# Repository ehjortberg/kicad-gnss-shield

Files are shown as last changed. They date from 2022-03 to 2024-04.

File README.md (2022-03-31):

# GNSS Shield
 - Should fit a Raspberry Pi 40 pin header or compatible.
 - Has footprints for Adafruits zedf9p, Navspark Mini, Navspark NS-HP, and Mikroe gnss-rtk-click
 - Has FTDI and HC-12 connectors for both UART1 and UART2 on the GNSS Modules
 - Connectes UART2 to Raspberry Pi 4 UART2

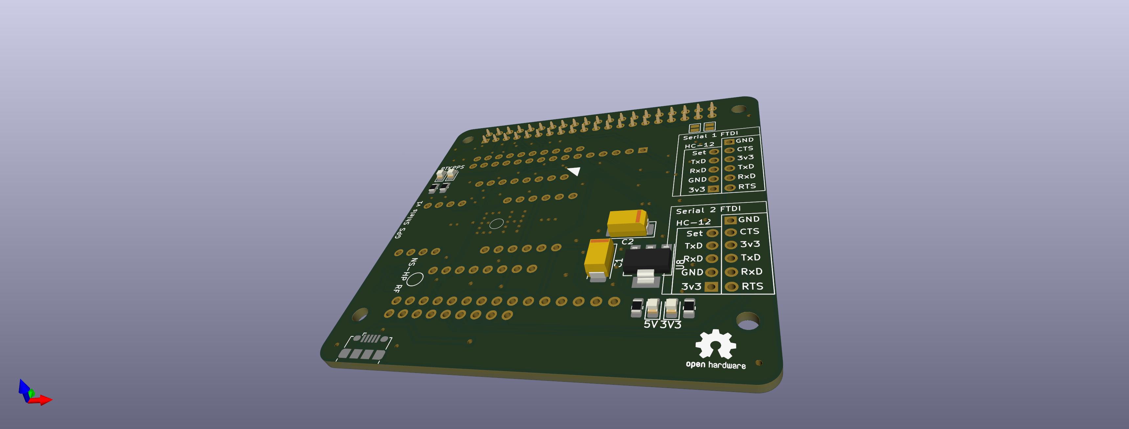
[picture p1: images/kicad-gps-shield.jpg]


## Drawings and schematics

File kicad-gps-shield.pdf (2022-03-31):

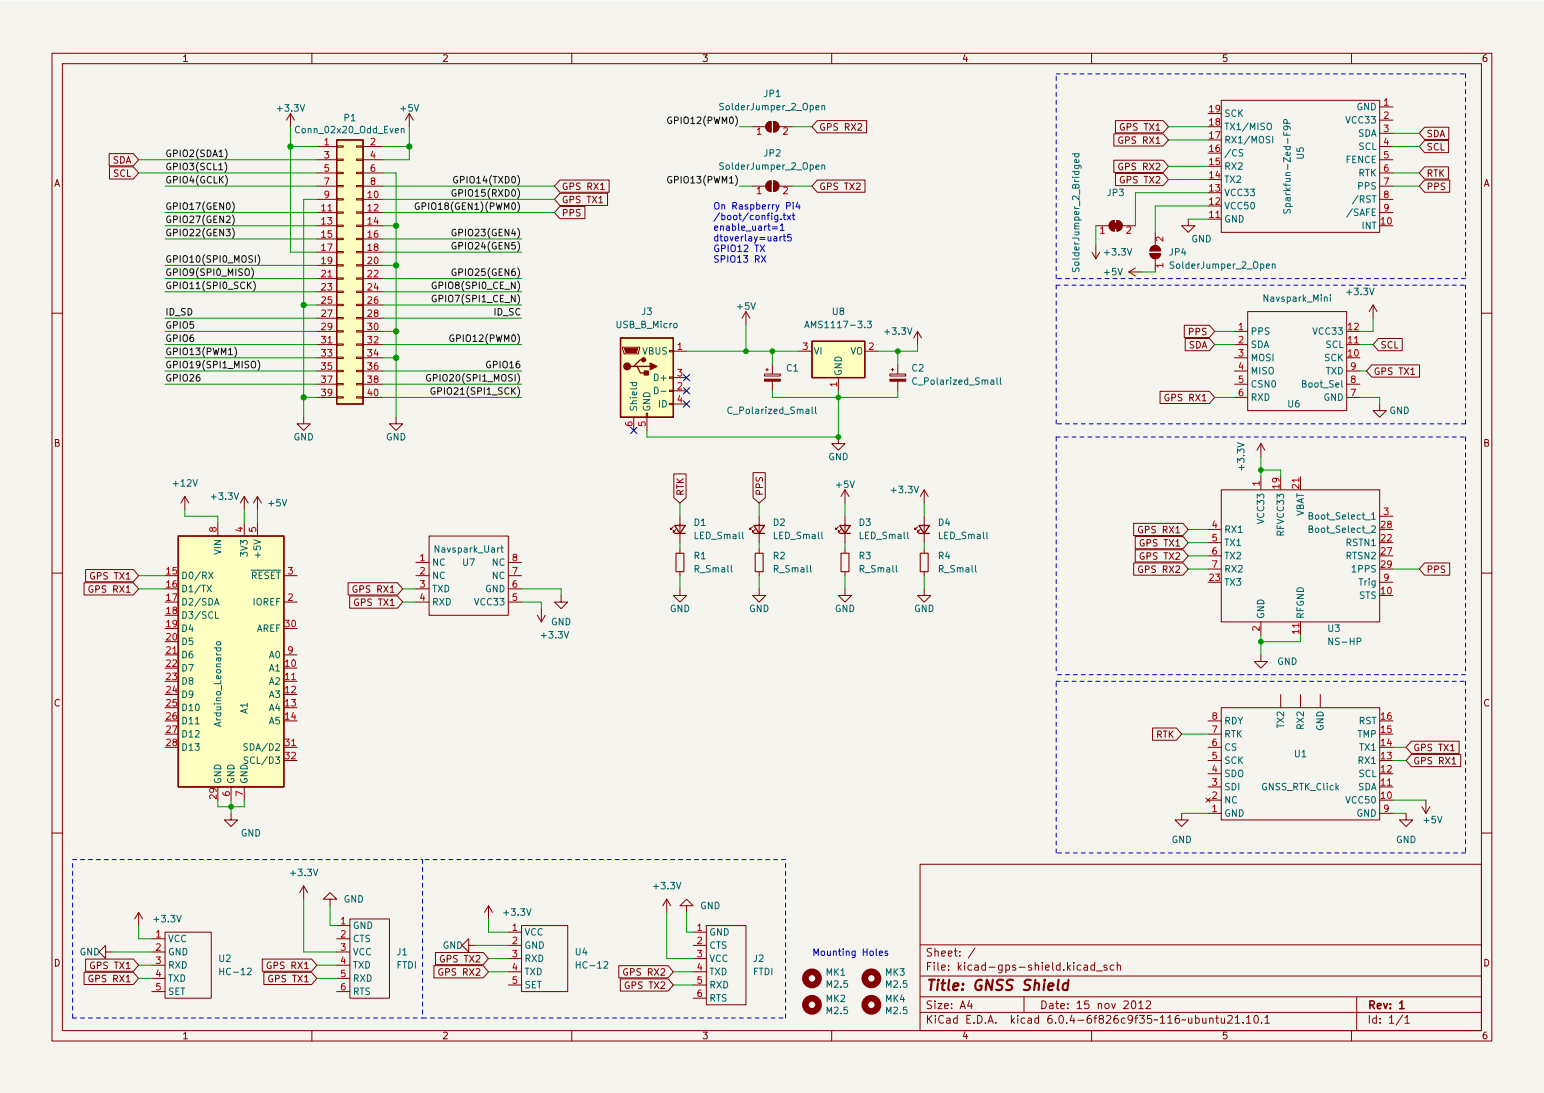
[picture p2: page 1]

GPS RX1 GPS RX2 GPS TX2 SDA

File: kicad-gps-shield.kicad_sch Sheet: / GND

15 | 16
17 | 18 | GPIO24(GEN5)
19 | 20 | GPIO25(GEN6)
21 | 22
23 | 24
25 | 26 | ID_SC GPIO7(SPI1_CE_N)
27 | 28
29 | 30
31 | 32
33 | 34
37 | 38 | GPIO21(SPI1_SCK) GPIO16 GPIO20(SPI1_MOSI)
35 | 36

Id: 1/1 Title: GNSS Shield

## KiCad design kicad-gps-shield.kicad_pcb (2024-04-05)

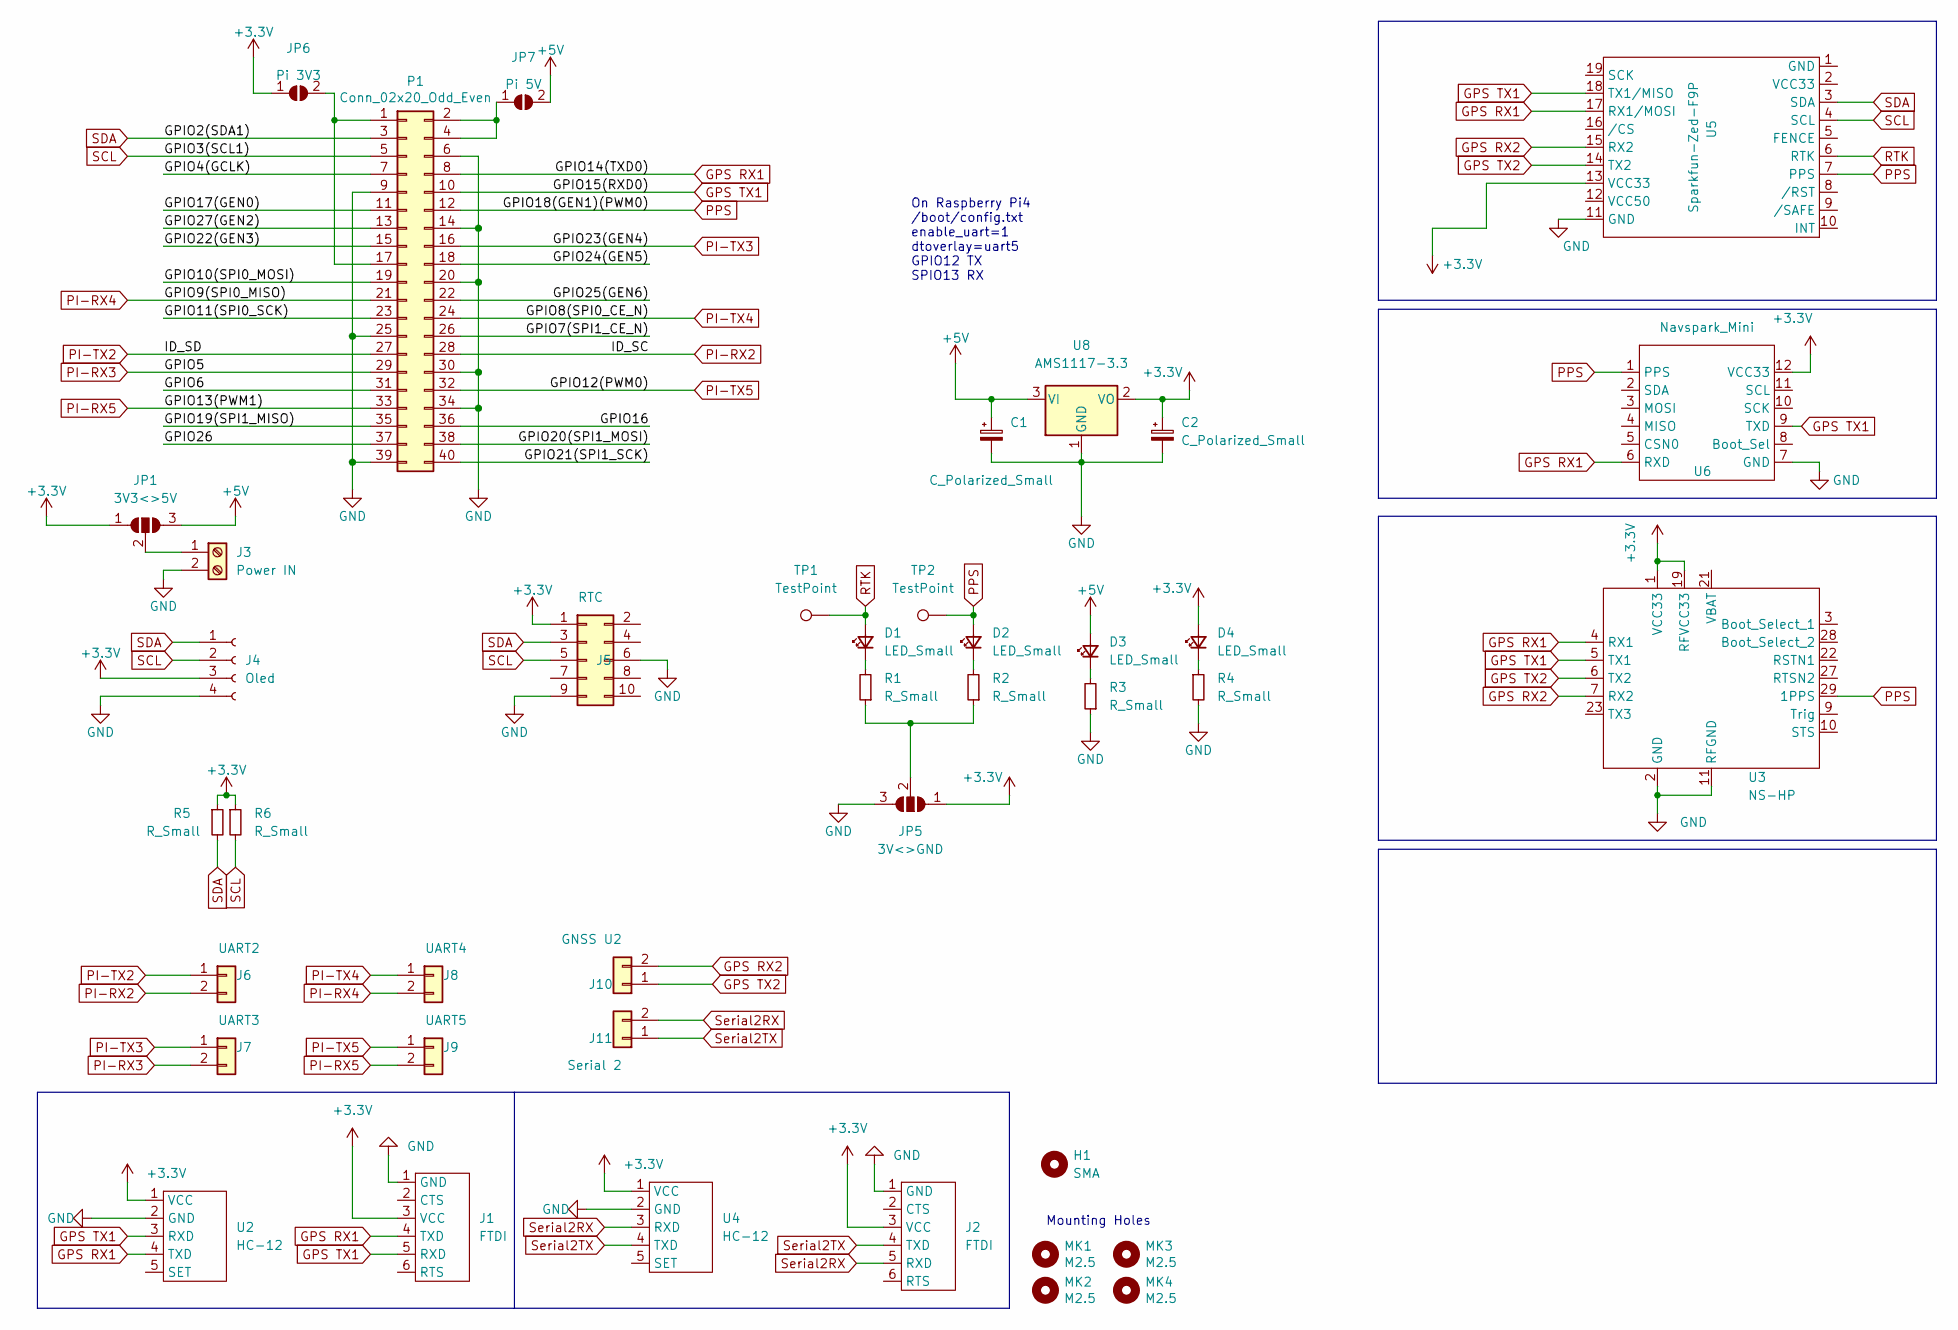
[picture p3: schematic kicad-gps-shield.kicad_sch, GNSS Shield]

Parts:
C1, C2: C_Polarized_Small; CP_EIA-6032-28_Kemet-C_Pad2.25x2.35mm_HandSolder
D1, D2, D3, D4: LED_Small; LED_0805_2012Metric_Pad1.15x1.40mm_HandSolder
H1: SMA; MountingHole_6.4mm_M6_ISO14580
J1, J2: FTDI
J3: Power IN; PinSocket_1x02_P2.54mm_Vertical
J4: Oled; PinSocket_1x04_P2.54mm_Vertical
J5: RTC; PinSocket_2x05_P2.54mm_Vertical
J6: UART2; PinSocket_1x02_P2.54mm_Vertical
J7: UART3; PinSocket_1x02_P2.54mm_Vertical
J8: UART4; PinSocket_1x02_P2.54mm_Vertical
J9: UART5; PinSocket_1x02_P2.54mm_Vertical
J10: GNSS U2; PinSocket_1x02_P2.54mm_Vertical
J11: Serial 2; PinSocket_1x02_P2.54mm_Vertical
JP1: 3V3<>5V; SolderJumper-3_P2.0mm_Open_TrianglePad1.0x1.5mm
JP5: 3V<>GND; SolderJumper-3_P2.0mm_Open_TrianglePad1.0x1.5mm
JP6: Pi 3V3; SolderJumper-2_P1.3mm_Open_TrianglePad1.0x1.5mm
JP7: Pi 5V; SolderJumper-2_P1.3mm_Open_TrianglePad1.0x1.5mm
MK1, MK2, MK3, MK4: M2.5; MountingHole_2.7mm_M2.5
P1: Conn_02x20_Odd_Even; PinSocket_2x20_P2.54mm_Vertical
R1, R2, R3, R4, R5, R6: R_Small; R_0805_2012Metric_Pad1.20x1.40mm_HandSolder
TP1, TP2: TestPoint; TestPoint_THTPad_2.5x2.5mm_Drill1.2mm
U2, U4: HC-12
U3: NS-HP
U5: Sparkfun-Zed-F9P; Sparkfun zed-f9p
U6: Navspark_Mini; Navspark Mini
U8: AMS1117-3.3; SOT-223-3_TabPin2

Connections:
+3V3: C2.1, D4.2 (A), J1.3 (VCC), J2.3 (VCC), J4.3, J5.1, JP1.1 (A), JP5.1 (A), JP6.1 (A), R5.1, R6.1, U2.1 (VCC), U3.1 (VCC33), U3.19 (RFVCC33), U3.20 (RFVCC33), U3.25 (VCC33), U4.1 (VCC), U5.13 (VCC33), U6.12 (VCC33), U8.2 (VO)
+5V: C1.1, D3.2 (A), JP1.3 (B), JP7.2 (B), U8.3 (VI)
/GPIO4(GCLK): P1.7
/GPIO6: P1.31
/GPIO7(SPI1_CE_N): P1.26
/GPIO10(SPI0_MOSI): P1.19
/GPIO11(SPI0_SCK): P1.23
/GPIO16: P1.36
/GPIO17(GEN0): P1.11
/GPIO19(SPI1_MISO): P1.35
/GPIO20(SPI1_MOSI): P1.38
/GPIO21(SPI1_SCK): P1.40
/GPIO22(GEN3): P1.15
/GPIO24(GEN5): P1.18
/GPIO25(GEN6): P1.22
/GPIO26: P1.37
/GPIO27(GEN2): P1.13
GND: C1.2, C2.2, J1.1 (GND), J2.1 (GND), J3.2, J4.4, J5.6, J5.9, JP5.3 (B), P1.6, P1.9, P1.14, P1.20, P1.25, P1.30, P1.34, P1.39, R3.1, R4.2, U2.2 (GND), U3.2 (GND), U3.11 (RFGND), U3.12 (RFGND), U3.16 (RFGND), U3.17 (RFGND), U3.18 (RFGND), U3.30 (GND), U4.2 (GND), U5.11 (GND), U6.7 (GND), U8.1 (GND)
GPS RX1: J1.4 (TXD), P1.8, U2.4 (TXD), U3.4 (RX1), U5.17 (RX1/MOSI), U6.6 (RXD)
GPS RX2: J10.2, U3.7 (RX2), U5.15 (RX2)
GPS TX1: J1.5 (RXD), P1.10, U2.3 (RXD), U3.5 (TX1), U5.18 (TX1/MISO), U6.9 (TXD)
GPS TX2: J10.1, U3.6 (TX2), U5.14 (TX2)
unnamed: D1.1 (K), R1.2
unnamed: D2.1 (K), R2.2
unnamed: D3.1 (K), R3.2
unnamed: D4.1 (K), R4.1
unnamed: J3.1, JP1.2 (C)
unnamed: JP5.2 (C), R1.1, R2.1
unnamed: JP6.2 (B), P1.1, P1.17
unnamed: JP7.1 (A), P1.2, P1.4
PI-RX2: J6.2, P1.28
PI-RX3: J7.2, P1.29
PI-RX4: J8.2, P1.21
PI-RX5: J9.2, P1.33
PI-TX2: J6.1, P1.27
PI-TX3: J7.1, P1.16
PI-TX4: J8.1, P1.24
PI-TX5: J9.1, P1.32
PPS: D2.2 (A), P1.12, TP2.1, U3.29 (1PPS), U5.7 (PPS), U6.1 (PPS)
RTK: D1.2 (A), TP1.1, U5.6 (RTK)
SCL: J4.2, J5.5, P1.5, R6.2, U5.4 (SCL)
SDA: J4.1, J5.3, P1.3, R5.2, U5.3 (SDA)
Serial2RX: J2.5 (RXD), J11.2, U4.3 (RXD)
Serial2TX: J2.4 (TXD), J11.1, U4.4 (TXD)

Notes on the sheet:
Mounting Holes
On Raspberry Pi4 /boot/config.txt enable_uart=1 dtoverlay=uart5 GPIO12 TX SPIO13 RX

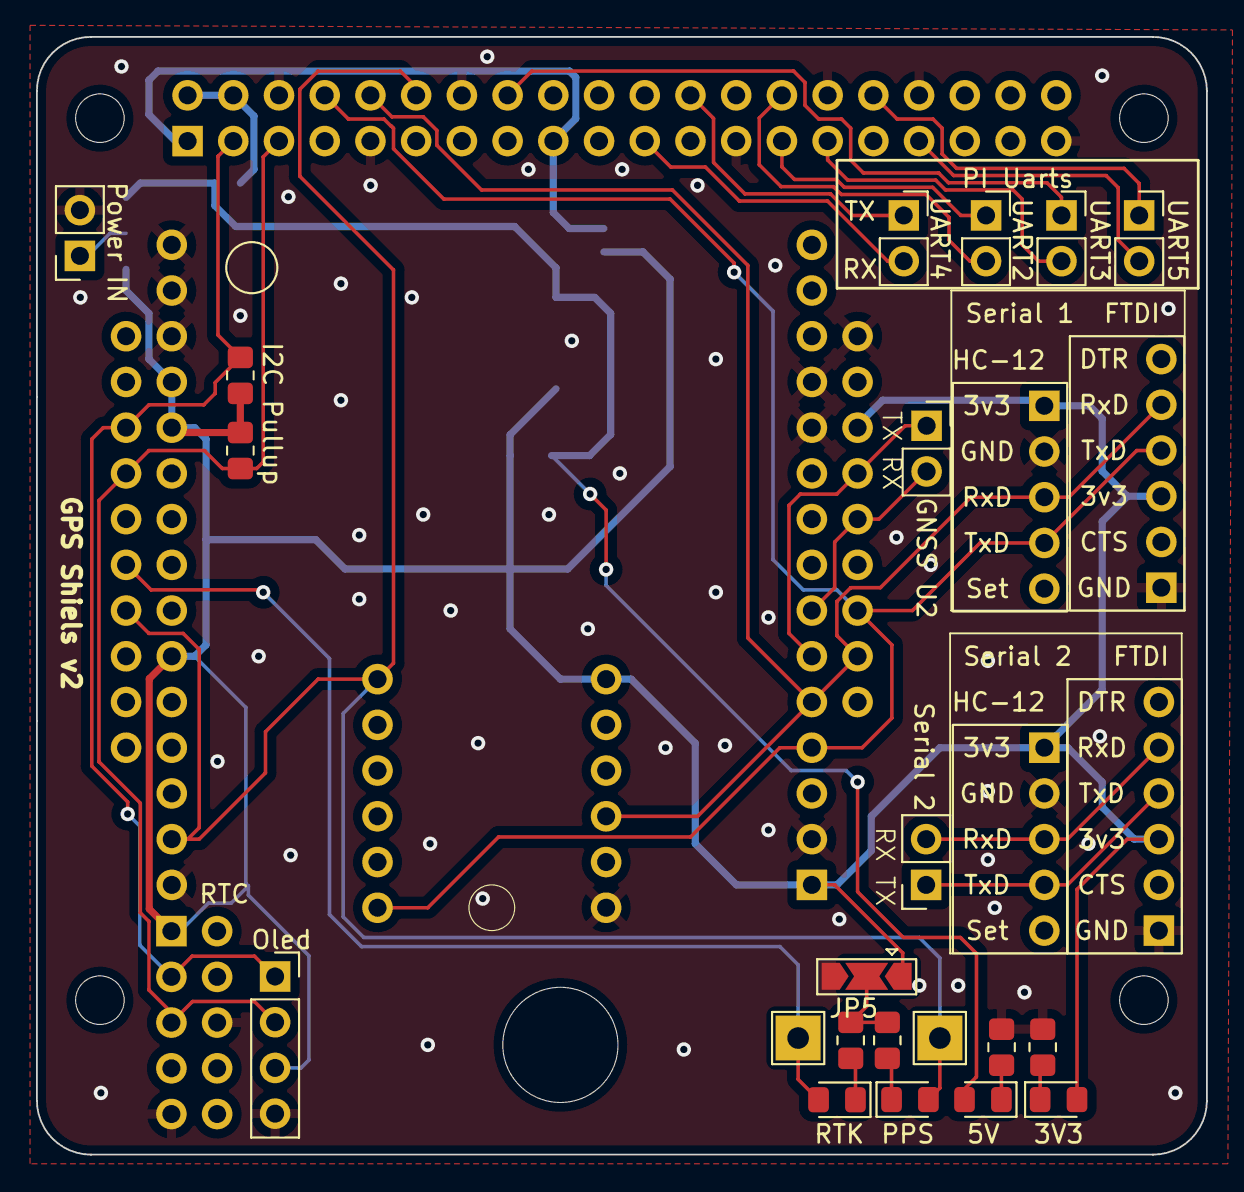
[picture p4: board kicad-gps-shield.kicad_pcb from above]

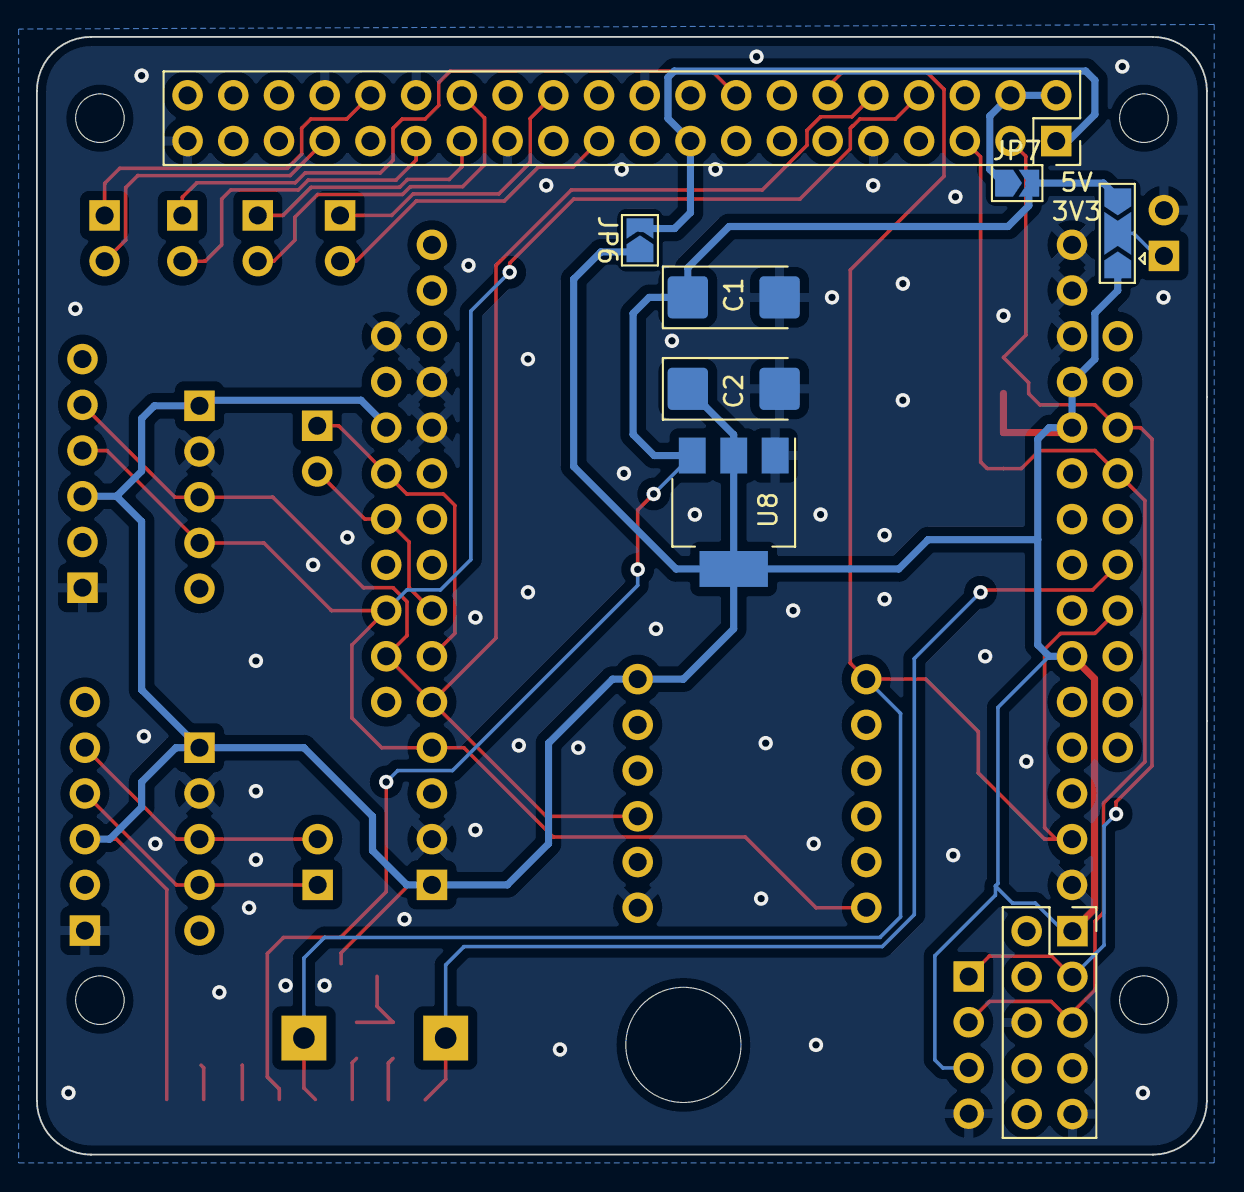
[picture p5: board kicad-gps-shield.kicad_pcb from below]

Board: 2 copper layers, 65.0 x 62.1 mm, 41 parts (8 on the bottom side), 29 nets.

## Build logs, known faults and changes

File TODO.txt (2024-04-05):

== Done in V2 ==
2nd, 3rd, 4th serialport breakoout.
Flip FTDI and HC-12 so normal 90deg angle is faceing the other way.
 Mark pins that need to be soldered with a box or ring.
Select Serial1/2 to raspberry, and also disable to raspberry.
HC-12 to raspberry. third port with tx/rx switched.
Hole for mounting SMA outside body
I2C for RTC Clock
Move 5v led resistor not to interfere with ns-hp female header.( Seems to be working)
RTK and PPS select Active high or active low. (gnd or 5v connection)
Sparkfun module pinout is wrong 
HC-12 mounted 90degrees over other stuff.
